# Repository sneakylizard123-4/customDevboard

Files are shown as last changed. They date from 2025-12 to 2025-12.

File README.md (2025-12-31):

# customDevboard
custom devboard made with RP 2040 in 30x30 flight controller size
PCB_matteblack2
file3

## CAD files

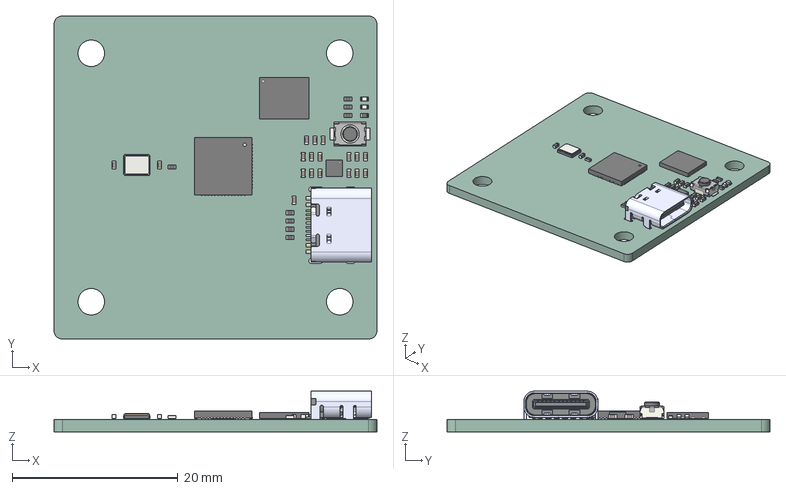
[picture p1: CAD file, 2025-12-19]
customDevboard.step
39.0 x 39.0 x 4.91 mm
WSON-8-1EP_6x5mm_P1.27mm_EP3.4x4.3mm
C_0402_1005Metric x 18
R_0402_1005Metric x 9
SW_Push_SPST_NO_Alps_SKRK
LED_0402_1005Metric x 2
QFN-56-1EP_7x7mm_P0.4mm_EP3.2x3.2mm
WSON-6-1EP_2x2mm_P0.65mm_EP1x1.6mm
TYPE-C-31-M-12
Crystal_SMD_3225-4Pin_3.2x2.5mm
customDevboard_PCB

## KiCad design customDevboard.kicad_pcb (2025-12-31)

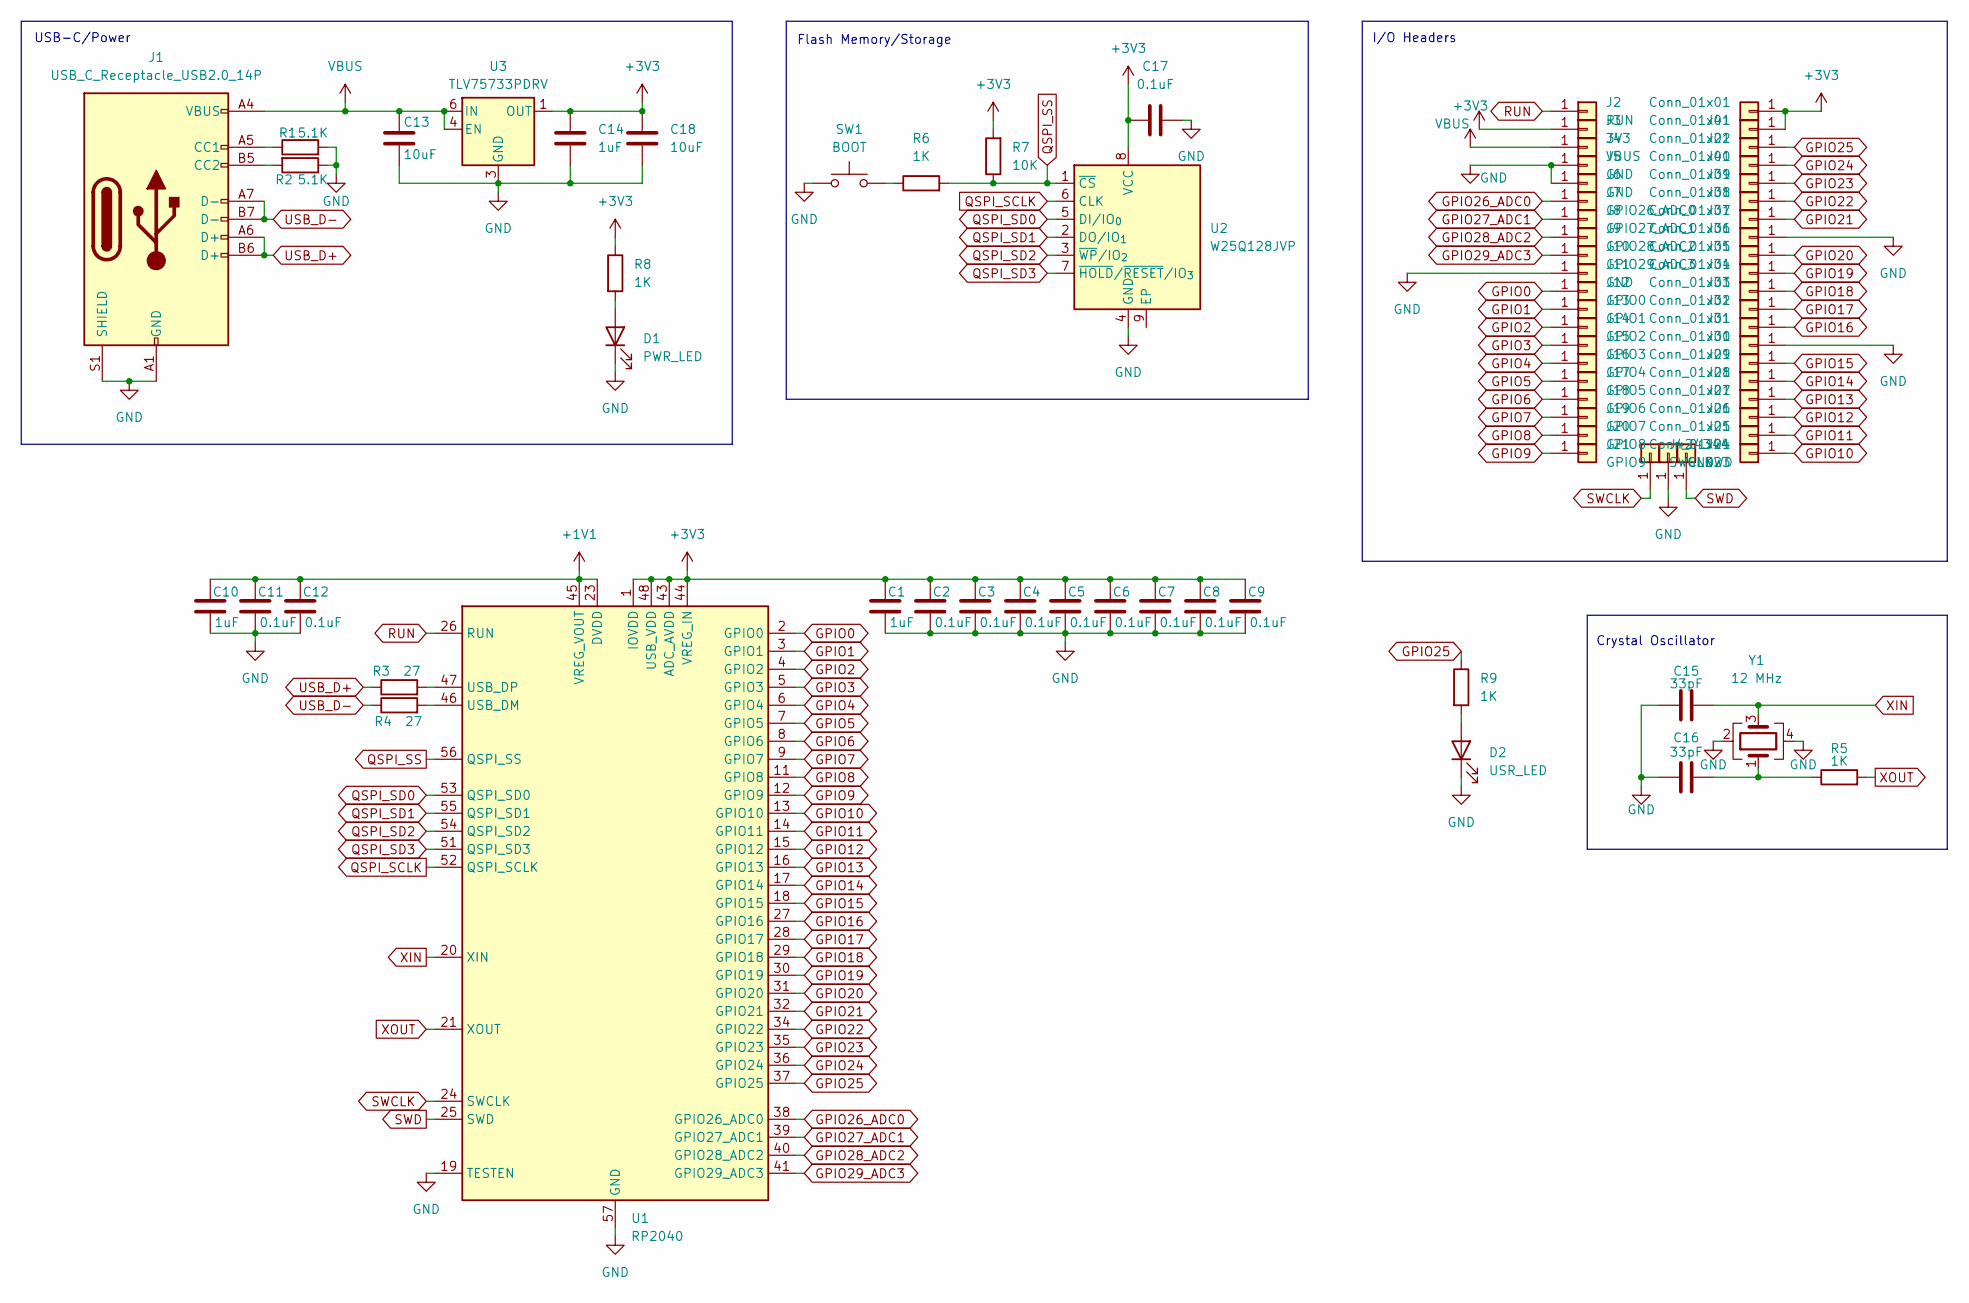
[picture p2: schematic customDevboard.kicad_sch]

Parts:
C1, C10, C14: 1uF; C_0402_1005Metric
C2, C3, C4, C5, C6, C7, C8, C9, C11, C12, C17: 0.1uF; C_0402_1005Metric
C13, C18: 10uF; C_0402_1005Metric
C15, C16: 33pF; C_0402_1005Metric
D1: PWR_LED; LED_0402_1005Metric
D2: USR_LED; LED_0402_1005Metric
J1: USB_C_Receptacle_USB2.0_14P; USB_C_Receptacle_HRO_TYPE-C-31-M-12
J2: RUN; SolderWirePad_1x01_SMD_1x2mm
J3: 3V3; SolderWirePad_1x01_SMD_1x2mm
J4: VBUS; SolderWirePad_1x01_SMD_1x2mm
J5, J6, J11, J43: GND; SolderWirePad_1x01_SMD_1x2mm
J7: GPIO26_ADC0; SolderWirePad_1x01_SMD_1x2mm
J8: GPIO27_ADC1; SolderWirePad_1x01_SMD_1x2mm
J9: GPIO28_ADC2; SolderWirePad_1x01_SMD_1x2mm
J10: GPIO29_ADC3; SolderWirePad_1x01_SMD_1x2mm
J12: GPIO0; SolderWirePad_1x01_SMD_1x2mm
J13: GPIO1; SolderWirePad_1x01_SMD_1x2mm
J14: GPIO2; SolderWirePad_1x01_SMD_1x2mm
J15: GPIO3; SolderWirePad_1x01_SMD_1x2mm
J16: GPIO4; SolderWirePad_1x01_SMD_1x2mm
J17: GPIO5; SolderWirePad_1x01_SMD_1x2mm
J18: GPIO6; SolderWirePad_1x01_SMD_1x2mm
J19: GPIO7; SolderWirePad_1x01_SMD_1x2mm
J20: GPIO8; SolderWirePad_1x01_SMD_1x2mm
J21: GPIO9; SolderWirePad_1x01_SMD_1x2mm
J22, J23, J24, J25, J26, J27, J28, J29, J30, J31, J32, J33, J34, J35, J36, J37, J38, J39, J40, J41: Conn_01x01; SolderWirePad_1x01_SMD_1x2mm
J42: SWCLK; SolderWirePad_1x01_SMD_1x2mm
J44: SWD; SolderWirePad_1x01_SMD_1x2mm
R1, R2: 5.1K; R_0402_1005Metric
R3, R4: 27; R_0402_1005Metric
R5, R6, R8, R9: 1K; R_0402_1005Metric
R7: 10K; R_0402_1005Metric
SW1: BOOT; SW_Push_SPST_NO_Alps_SKRK
U1: RP2040; QFN-56-1EP_7x7mm_P0.4mm_EP3.2x3.2mm
U2: W25Q128JVP; WSON-8-1EP_6x5mm_P1.27mm_EP3.4x4.3mm
U3: TLV75733PDRV; WSON-6-1EP_2x2mm_P0.65mm_EP1x1.6mm
Y1: 12 MHz; Crystal_SMD_3225-4Pin_3.2x2.5mm

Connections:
+1V1: C10.1, C11.1, C12.1, U1.23 (DVDD), U1.45 (VREG_VOUT), U1.50 (DVDD)
+3V3: C1.1, C2.1, C3.1, C4.1, C5.1, C6.1, C7.1, C8.1, C9.1, C14.1, C17.1, C18.1, J3.1, J22.1, J41.1, R7.2, R8.1, U1.1 (IOVDD), U1.10 (IOVDD), U1.22 (IOVDD), U1.33 (IOVDD), U1.42 (IOVDD), U1.43 (ADC_AVDD), U1.44 (VREG_IN), U1.48 (USB_VDD), U1.49 (IOVDD), U2.8 (VCC), U3.1 (OUT)
GND: C1.2, C2.2, C3.2, C4.2, C5.2, C6.2, C7.2, C8.2, C9.2, C10.2, C11.2, C12.2, C13.2, C14.2, C15.1, C16.1, C17.2, C18.2, D1.1 (K), D2.1 (K), J1.A1 (GND), J1.A12 (GND), J1.B1 (GND), J1.B12 (GND), J1.S1 (SHIELD), J5.1, J6.1, J11.1, J29.1, J35.1, J43.1, R1.2, R2.1, SW1.1, U1.19 (TESTEN), U1.57 (GND), U2.4 (GND), U3.3 (GND), U3.7 (GND), Y1.2, Y1.4
GPIO0: J12.1, U1.2 (GPIO0)
GPIO1: J13.1, U1.3 (GPIO1)
GPIO2: J14.1, U1.4 (GPIO2)
GPIO3: J15.1, U1.5 (GPIO3)
GPIO4: J16.1, U1.6 (GPIO4)
GPIO5: J17.1, U1.7 (GPIO5)
GPIO6: J18.1, U1.8 (GPIO6)
GPIO7: J19.1, U1.9 (GPIO7)
GPIO8: J20.1, U1.11 (GPIO8)
GPIO9: J21.1, U1.12 (GPIO9)
GPIO10: J23.1, U1.13 (GPIO10)
GPIO11: J24.1, U1.14 (GPIO11)
GPIO12: J25.1, U1.15 (GPIO12)
GPIO13: J26.1, U1.16 (GPIO13)
GPIO14: J27.1, U1.17 (GPIO14)
GPIO15: J28.1, U1.18 (GPIO15)
GPIO16: J30.1, U1.27 (GPIO16)
GPIO17: J31.1, U1.28 (GPIO17)
GPIO18: J32.1, U1.29 (GPIO18)
GPIO19: J33.1, U1.30 (GPIO19)
GPIO20: J34.1, U1.31 (GPIO20)
GPIO21: J36.1, U1.32 (GPIO21)
GPIO22: J37.1, U1.34 (GPIO22)
GPIO23: J38.1, U1.35 (GPIO23)
GPIO24: J39.1, U1.36 (GPIO24)
GPIO25: J40.1, R9.1, U1.37 (GPIO25)
GPIO26_ADC0: J7.1, U1.38 (GPIO26_ADC0)
GPIO27_ADC1: J8.1, U1.39 (GPIO27_ADC1)
GPIO28_ADC2: J9.1, U1.40 (GPIO28_ADC2)
GPIO29_ADC3: J10.1, U1.41 (GPIO29_ADC3)
unnamed: C16.2, R5.1, Y1.1
unnamed: D1.2 (A), R8.2
unnamed: D2.2 (A), R9.2
unnamed: J1.A5 (CC1), R1.1
unnamed: J1.B5 (CC2), R2.2
unnamed: R6.1, SW1.2
unnamed: R4.2, U1.46 (USB_DM)
unnamed: R3.2, U1.47 (USB_DP)
QSPI_SCLK: U1.52 (QSPI_SCLK), U2.6 (CLK)
QSPI_SD0: U1.53 (QSPI_SD0), U2.5 (DI/IO_{0})
QSPI_SD1: U1.55 (QSPI_SD1), U2.2 (DO/IO_{1})
QSPI_SD2: U1.54 (QSPI_SD2), U2.3 (~WP/IO_{2})
QSPI_SD3: U1.51 (QSPI_SD3), U2.7 (~HOLD/~RESET/IO_{3})
QSPI_SS: R6.2, R7.1, U1.56 (QSPI_SS), U2.1 (~CS)
RUN: J2.1, U1.26 (RUN)
SWCLK: J42.1, U1.24 (SWCLK)
SWD: J44.1, U1.25 (SWD)
USB_D+: J1.A6 (D+), J1.B6 (D+), R3.1
USB_D-: J1.A7 (D-), J1.B7 (D-), R4.1
VBUS: C13.1, J1.A4 (VBUS), J1.A9 (VBUS), J1.B4 (VBUS), J1.B9 (VBUS), J4.1, U3.4 (EN), U3.6 (IN)
XIN: C15.2, U1.20 (XIN), Y1.3
XOUT: R5.2, U1.21 (XOUT)

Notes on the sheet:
USB-C/Power
Crystal Oscillator
Flash Memory/Storage
I/O Headers

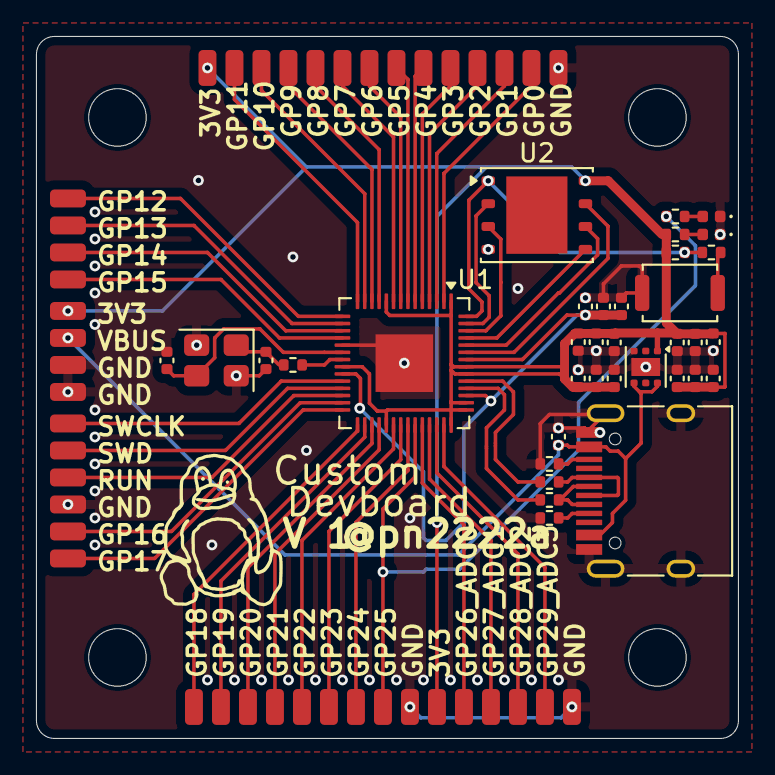
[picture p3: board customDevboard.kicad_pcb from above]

Board: 2 copper layers, 39.0 x 39.0 mm, 78 parts (0 on the bottom side), 55 nets.

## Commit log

2025-12-12 It works! I hope
    [customDevboard.kicad_pcb, customDevboard.kicad_sch]
2025-12-13 V1 testing release
    [customDevboard.kicad_pcb]
2025-12-15 fixed mounting hole size
    [customDevboard.kicad_pcb]
2025-12-15 fixed mounting holes
2025-12-16 update pcb with mounting holes
    [customDevboard.kicad_pcb]
2025-12-19 step file
    [customDevboard.step]
2025-12-24 update pcb
    [customDevboard.kicad_pcb]
